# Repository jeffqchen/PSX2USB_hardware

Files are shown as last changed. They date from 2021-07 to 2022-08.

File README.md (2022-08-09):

# PSX2USB_hardware

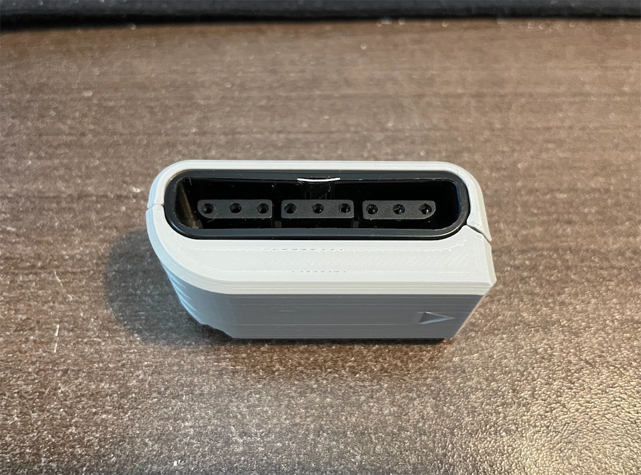
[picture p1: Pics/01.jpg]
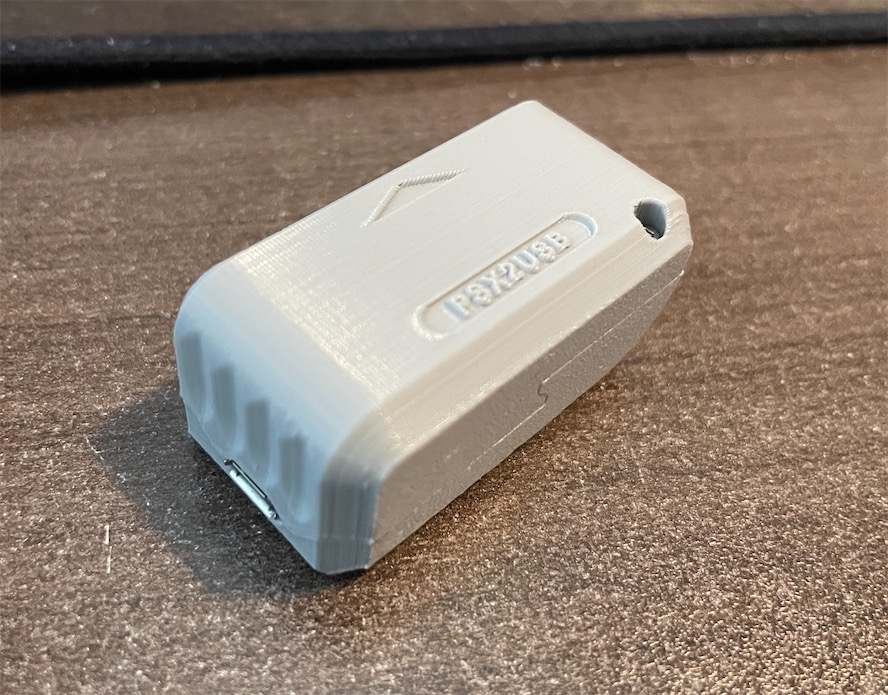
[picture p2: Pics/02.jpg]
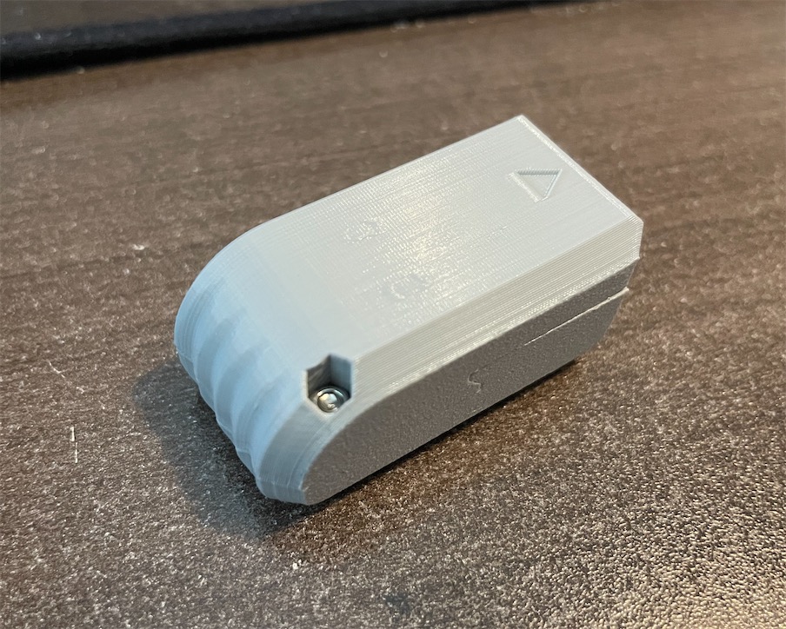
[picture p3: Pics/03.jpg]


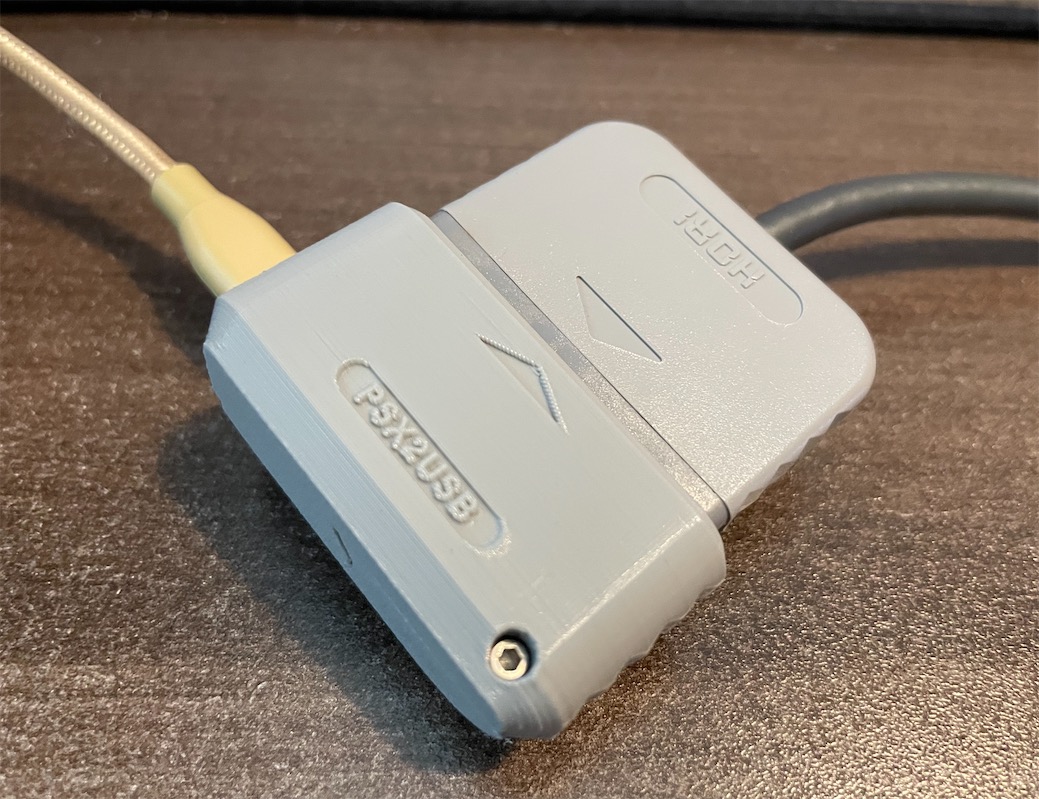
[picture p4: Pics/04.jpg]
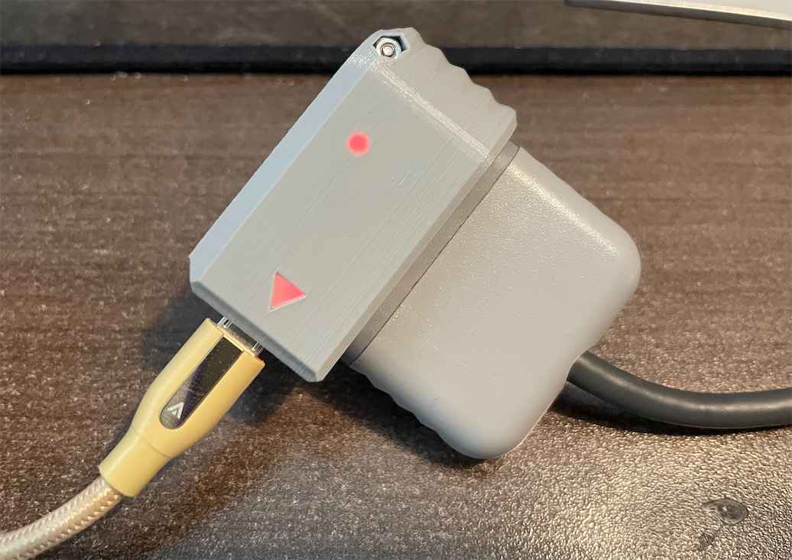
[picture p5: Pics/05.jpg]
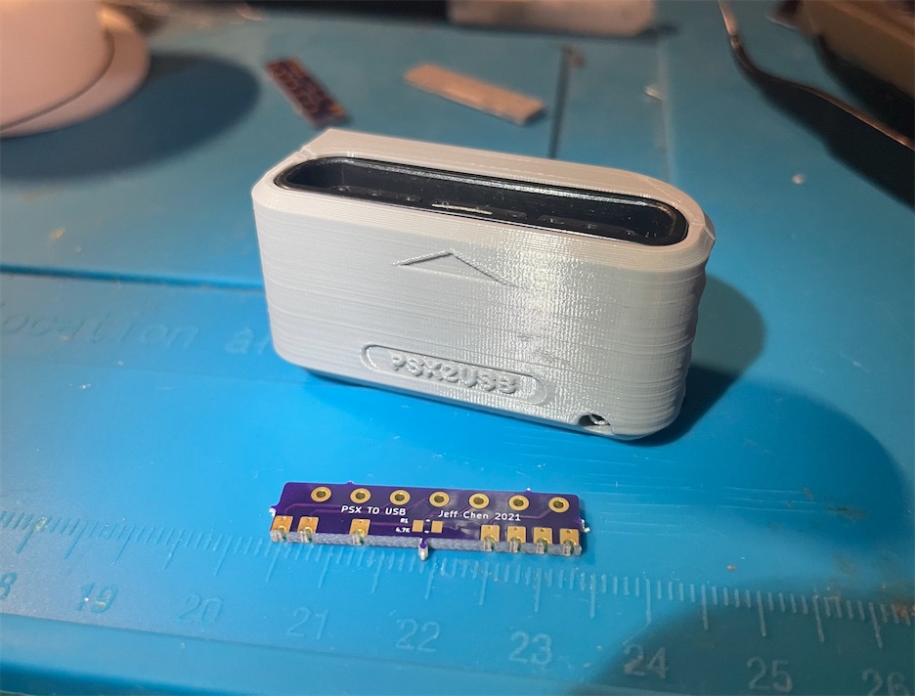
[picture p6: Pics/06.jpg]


This is my iteration of a PSX to USB controller adapter. It uses an Arduino Pro Micro as the micro controller. The 3D printed shell packs everything very tight together. Important LEDs shine through hidden windows on the shell.

-------------
## Parts

- [PCB](https://oshpark.com/shared_projects/5XfiUruJ)

- PlayStation Controller Port - [Link](https://github.com/jeffqchen/JeffParts/blob/main/Connectors/PlayStation%20Controller%20Port/info.md)

- Arduino Pro Micro (Preferably 3.3V version) - [Link](https://github.com/jeffqchen/JeffParts/blob/main/Board/Arduino/Pro%20Micro/3.3V%208MHz/info.md)

- [1x] M2x12 Hex screw & nut - [Link](https://github.com/jeffqchen/JeffParts/blob/main/Parts/M2%20M3%20Hex%20Screw%20%26%20Nut/info.md)

- [1x] 0603 size 4.7K SMD resistor

-------------

## Printing

Print the two sides upright with support. That's it.

-------------

## Assembly

Snip off pin 9 flush from the PSX controller plug.

Solder the 4.7K 0603 resistor onto the PCB.

The connection between the Arduino and the PCB is through castellated holes. They are a bit tricky to solder.

Lightly tin both sides of the castellated holes and pads on the PCB before hand. Then, slide the PCB onto the controller plug (mind the orientation, the 4.7K resistor should be visible), then solder the PCB onto the plug, as close as possible to the root of the pins.

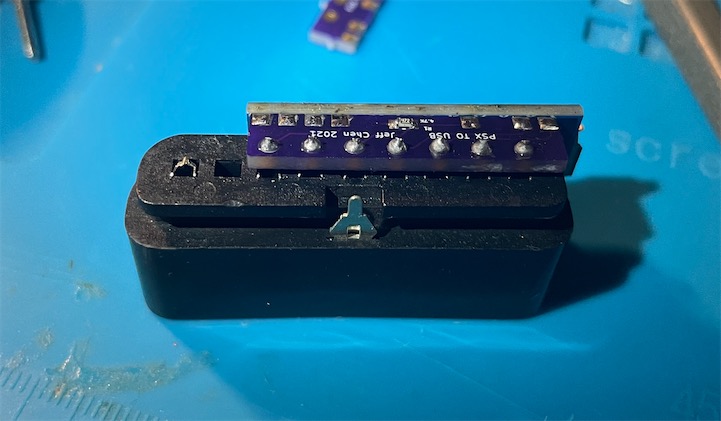
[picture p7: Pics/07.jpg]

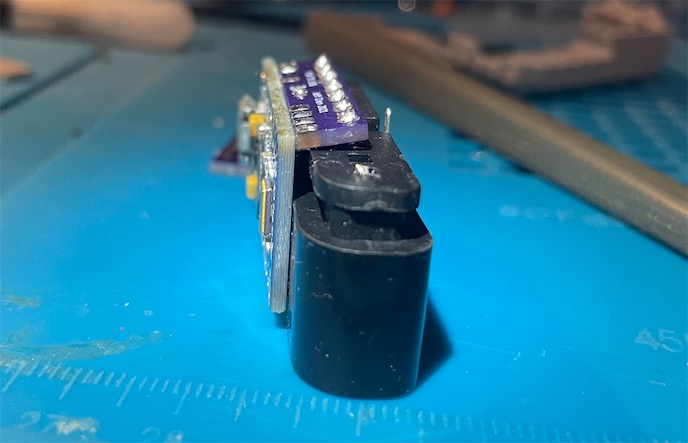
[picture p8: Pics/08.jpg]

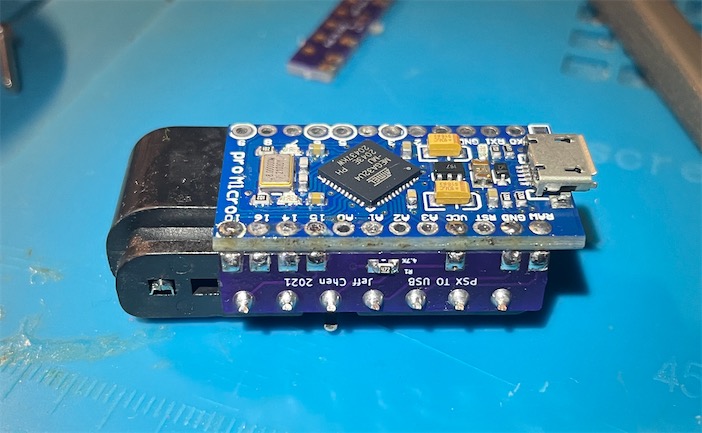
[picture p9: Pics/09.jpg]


Snap the assembly into the 3D-printed plug side part. Put a piece of thin double-sided tape on the exposed side of the plug, then put the Arduino in place.

Then, feed solder into the corresponding holes on the Arduino, while watching when the castelled holes on the PCB start to wet/melt. That indicates the solder has connected. Becareful not to melt the 3D printed shell. Don't heat things up for too long in one go.

Remember to test continuity of these joints with a multimeter before closing up.

-------------

## Software

Find information about the software portion in this repo:
https://github.com/jeffqchen/PSX2USB_software

-------------

Shield: [][cc-by-sa]

This work is licensed under a
[Creative Commons Attribution-ShareAlike 4.0 International License][cc-by-sa].

[][cc-by-sa]

[cc-by-sa]: http://creativecommons.org/licenses/by-sa/4.0/
[cc-by-sa-image]: https://licensebuttons.net/l/by-sa/4.0/88x31.png
[cc-by-sa-shield]: https://img.shields.io/badge/License-CC%20BY--SA%204.0-lightgrey.svg

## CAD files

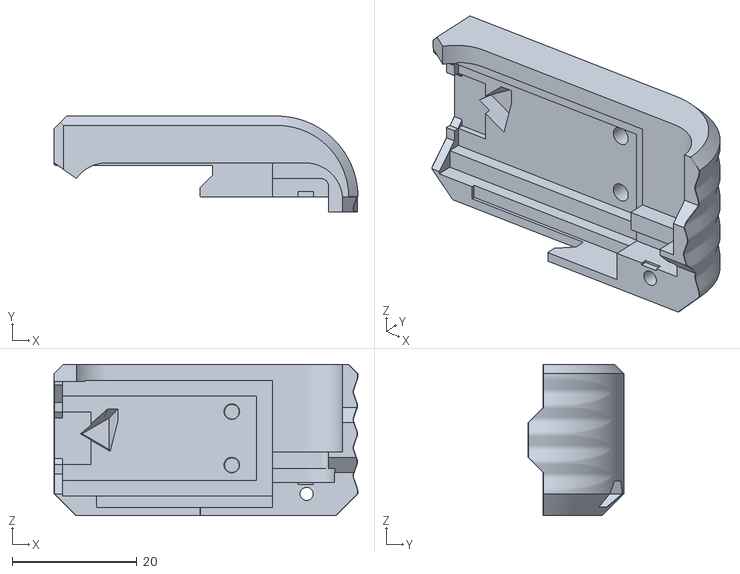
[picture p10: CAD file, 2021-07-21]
3D Print/Arduino Side.stl
48.8 x 15.4 x 24.3

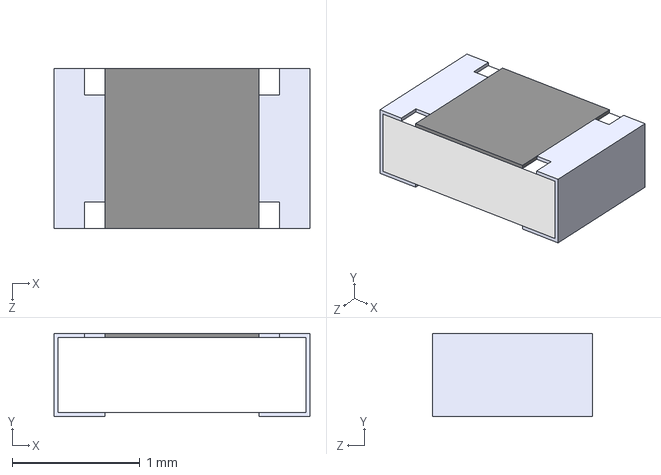
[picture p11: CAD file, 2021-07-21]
KiCAD/Files/CRGCQ0805J22R/CRGCQ0805J22R.step
2.00 x 0.65 x 1.25 mm

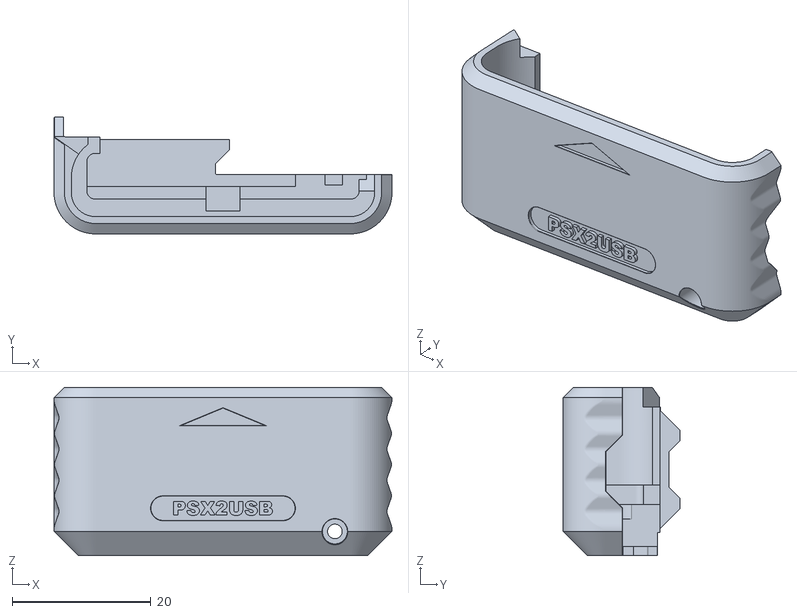
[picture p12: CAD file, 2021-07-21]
3D Print/Plug Side.stl
48.8 x 16.9 x 24.3

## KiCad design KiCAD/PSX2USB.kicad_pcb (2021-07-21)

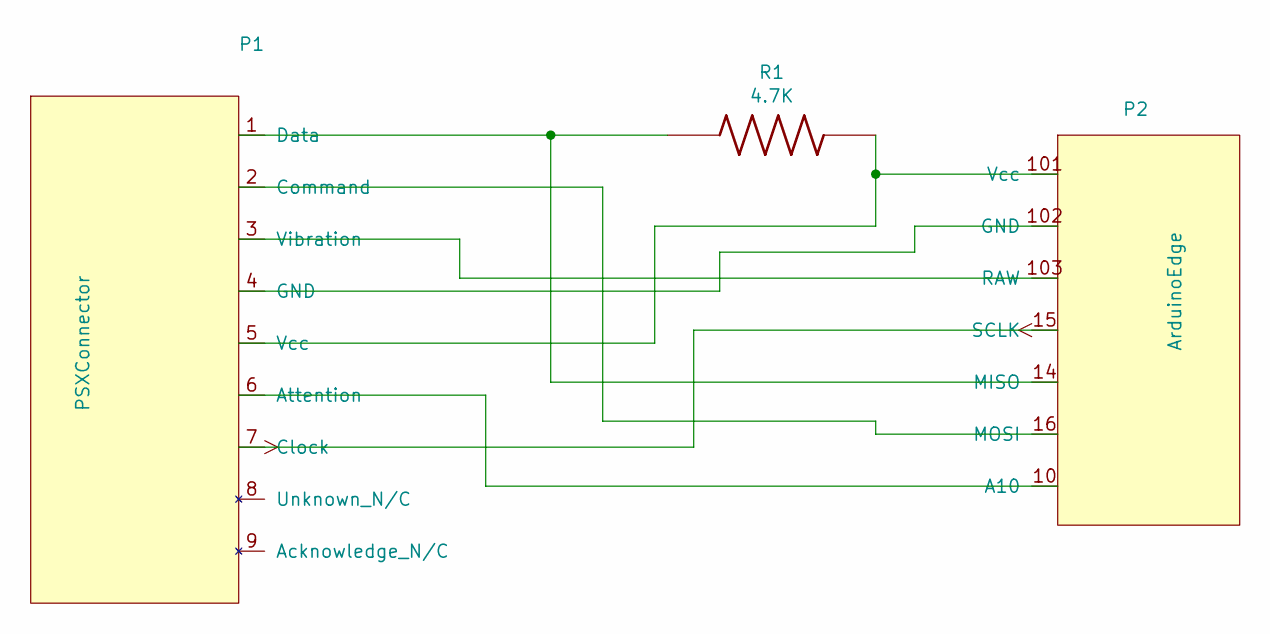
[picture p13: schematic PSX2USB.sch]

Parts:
P1: PSXConnector; PSX Controller
P2: ArduinoEdge; Arduino Edge
R1: 4.7K; Resistor

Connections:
unnamed: P1.1 (Data), P2.14 (MISO), R1.1
unnamed: P1.2 (Command), P2.16 (MOSI)
unnamed: P1.3 (Vibration), P2.103 (RAW)
unnamed: P1.4 (GND), P2.102 (GND)
unnamed: P1.5 (Vcc), P2.101 (Vcc), R1.2
unnamed: P1.6 (Attention), P2.10 (A10)
unnamed: P1.7 (Clock), P2.15 (SCLK)

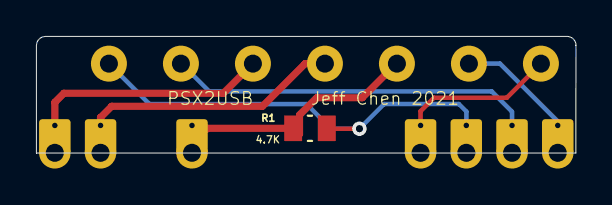
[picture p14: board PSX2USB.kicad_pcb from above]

Board: 2 copper layers, 30.0 x 6.5 mm, 3 parts (0 on the bottom side), 7 nets.

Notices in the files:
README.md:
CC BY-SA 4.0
